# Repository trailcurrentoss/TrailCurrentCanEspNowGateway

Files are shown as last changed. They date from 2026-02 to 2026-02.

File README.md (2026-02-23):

# TrailCurrent CAN to ESP-NOW Gateway

A wireless relay gateway that bridges CAN bus messages to ESP-NOW protocol for remote vehicle monitoring in tow vehicles. Part of the [TrailCurrent](https://trailcurrent.com) open-source vehicle platform.

## Overview

This project enables wireless relaying of CAN bus messages using the ESP-NOW protocol. The gateway hardware and firmware allow real-time data from a trailer's CAN bus to be transmitted reliably to remote displays and monitoring devices in a vehicle.

**Use Case:** Display trailer sensor data (battery voltage, temperature, weight sensors, etc.) on an in-vehicle display while the vehicle and trailer are separated or connected.

## Hardware Overview

- **Function:** Bidirectional CAN-to-ESP-NOW gateway with wireless relay capability
- **Key Features:**
  - CAN bus interface for trailer systems
  - ESP32 with integrated WiFi for robust wireless communication
  - ESP-NOW protocol for low-latency, long-range communication
  - Power management for vehicle and trailer power systems
  - Hierarchical schematic design (5 sheets) for system modularity
  - Compact design for integration into vehicle tow systems

## Hardware Requirements

### Components

- **Microcontroller:**
  - ESP32-WROOM or ESP32-S3 with WiFi and Bluetooth

- **CAN Interface:**
  - CAN transceiver for reliable CAN bus communication
  - Protection circuits for robust automotive operation

- **Power Management:**
  - Buck converter (AP63203WU-7) for regulated power supply
  - Filtering and protection circuits

- **Connectors:**
  - CAN bus interface connectors
  - Power connectors
  - Debug/programming connectors

### KiCAD Library Dependencies

This project uses the consolidated [TrailCurrentKiCADLibraries](https://github.com/trailcurrentoss/TrailCurrentKiCADLibraries).

**Setup:**

```bash
# Clone the library
git clone git@github.com:trailcurrentoss/TrailCurrentKiCADLibraries.git

# Set environment variables (add to ~/.bashrc or ~/.zshrc)
export TRAILCURRENT_SYMBOL_DIR="/path/to/TrailCurrentKiCADLibraries/symbols"
export TRAILCURRENT_FOOTPRINT_DIR="/path/to/TrailCurrentKiCADLibraries/footprints"
export TRAILCURRENT_3DMODEL_DIR="/path/to/TrailCurrentKiCADLibraries/3d_models"
```

See [KICAD_ENVIRONMENT_SETUP.md](https://github.com/trailcurrentoss/TrailCurrentKiCADLibraries/blob/main/KICAD_ENVIRONMENT_SETUP.md) in the library repository for detailed setup instructions.

## Opening the Project

1. **Set up environment variables** (see Library Dependencies above)
2. **Open KiCAD:**
   ```bash
   kicad /path/to/EDA/trailecurrent-can-to-espnow-gateway/trailecurrent-can-to-espnow-gateway.kicad_pro
   ```
3. **Verify libraries load** - All symbol and footprint libraries should resolve without errors
4. **Navigate hierarchical sheets:**
   - Main gateway sheet with module interconnects
   - CAN interface circuit (isolation and termination)
   - ESP32 microcontroller and WiFi section
   - Power management circuits
   - Support and protection circuits
5. **View 3D models** - Open PCB and press `Alt+3` to view the 3D visualization
   - All 3D models should load from the consolidated library path
   - Models use relative `${TRAILCURRENT_3DMODEL_DIR}` references

## Firmware

See `src/` directory for PlatformIO-based firmware implementing CAN-to-ESP-NOW bridging.

**Key Features:**
- CAN message reception and parsing
- ESP-NOW wireless transmission
- Bidirectional communication capability
- Configuration management for CAN filters and routing
- Low-power sleep modes for extended battery life

**Setup:**
```bash
# Install PlatformIO (if not already installed)
pip install platformio

# Build firmware
pio run -d /path/to/project

# Upload to board
pio run -t upload -d /path/to/project

# Monitor serial output
pio device monitor -d /path/to/project
```

**WiFi Credentials:**

The gateway requires WiFi credentials for OTA updates and network communication.

- **Production**: WiFi credentials are delivered via CAN Bus (ID 0x01) from the TrailCurrent system
- **Development**: For standalone testing without the TrailCurrent system, create `src/secrets.h`:

```bash
# Copy the example template
cp src/secrets.h.example src/secrets.h

# Edit with your WiFi credentials
nano src/secrets.h
```

```cpp
// src/secrets.h (DO NOT COMMIT - it's in .gitignore)
const char* ssid = "YOUR_SSID_HERE";
const char* password = "YOUR_PASSWORD_HERE";
uint8_t broadcastAddress[] = {0xXX, 0xXX, 0xXX, 0xXX, 0xXX, 0xXX};
```

**Important:**
- Never commit `src/secrets.h` (it's in .gitignore)
- Use `src/secrets.h.example` as a template
- The gateway MAC address should match your hardware

**Future Enhancement:** WiFi credential configuration will be fully implemented via CAN Bus protocol, allowing credentials to be distributed from the TrailCurrent system without firmware modifications.

## System Architecture

The gateway architecture:

1. **CAN Interface:** Receives messages from trailer CAN bus
2. **ESP32 Processor:** Parses and routes messages based on configured rules
3. **ESP-NOW Radio:** Transmits to remote devices with low latency
4. **Remote Device:** Receives and displays trailer data

Supports multiple remote devices through ESP-NOW group addressing.

## Manufacturing

- **PCB Files:** Ready for fabrication via standard PCB services (JLCPCB, OSH Park, etc.)
- **BOM Generation:** Export BOM from KiCAD schematic (Tools → Generate BOM)
- **JLCPCB Assembly:** This project supports automated assembly using JLCPCB
  - See [BOM_ASSEMBLY_WORKFLOW.md](https://github.com/trailcurrentoss/TrailCurrentKiCADLibraries/blob/main/BOM_ASSEMBLY_WORKFLOW.md) for detailed assembly workflow
  - Component library includes LCSC, Mouser, and DigiKey part numbers for flexible sourcing

## Project Structure

- **EDA/trailecurrent-can-to-espnow-gateway/** - KiCAD schematic (5 sheets) and PCB design files
  - Gateway main sheet with module organization
  - CAN interface and protection circuits
  - ESP32 microcontroller and radio circuits
  - Power management and support circuits
- **src/** - Firmware source code for CAN message bridging and ESP-NOW communication
- **lib/** - Custom libraries and CAN protocol drivers
- **include/** - Header files for configuration and messaging

## Documentation

- **Main Schematic:** EDA/trailecurrent-can-to-espnow-gateway/trailecurrent-can-to-espnow-gateway.kicad_sch (with 5 sheet hierarchy)
- **PCB Layout:** EDA/trailecurrent-can-to-espnow-gateway/trailecurrent-can-to-espnow-gateway.kicad_pcb

## License

MIT License - See LICENSE file for details

This is open source hardware. You are free to use, modify, and distribute these designs for personal or commercial purposes.

## Contributing

Improvements and contributions are welcome! Please submit issues or pull requests to the main repository.

## Support

For questions about:
- **KiCAD setup:** See [KICAD_ENVIRONMENT_SETUP.md](https://github.com/trailcurrentoss/TrailCurrentKiCADLibraries/blob/main/KICAD_ENVIRONMENT_SETUP.md)
- **Library consolidation:** See [CONNECTOR_CONSOLIDATION_SUMMARY.md](https://github.com/trailcurrentoss/TrailCurrentKiCADLibraries/blob/main/CONNECTOR_CONSOLIDATION_SUMMARY.md)
- **Assembly workflow:** See [BOM_ASSEMBLY_WORKFLOW.md](https://github.com/trailcurrentoss/TrailCurrentKiCADLibraries/blob/main/BOM_ASSEMBLY_WORKFLOW.md)

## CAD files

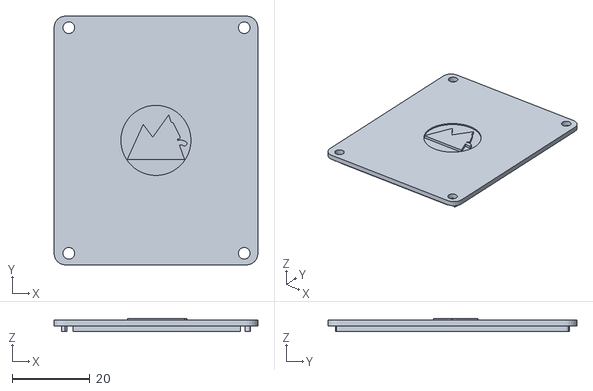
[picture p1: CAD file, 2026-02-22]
CAD/BodyCanToEspNowGatewayCaseCoverV1_WithLogo.stl
52.4 x 64.0 x 3.40

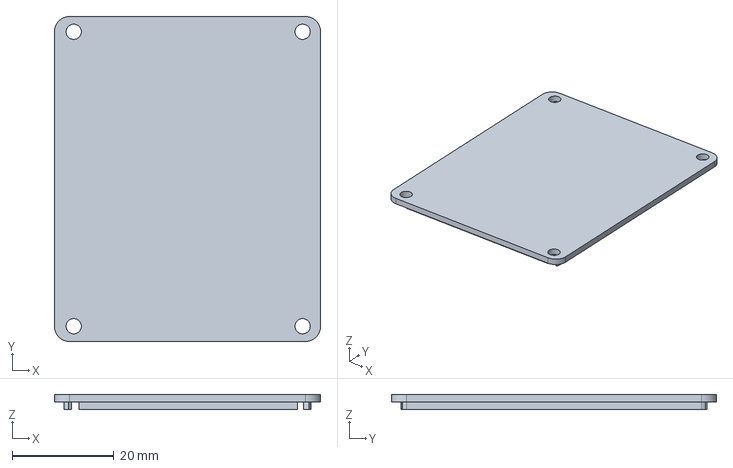
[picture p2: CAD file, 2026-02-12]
CAD/trailcurrent-can-to-espnow-gateway.FCStd
52.4 x 64.0 x 3.00 mm

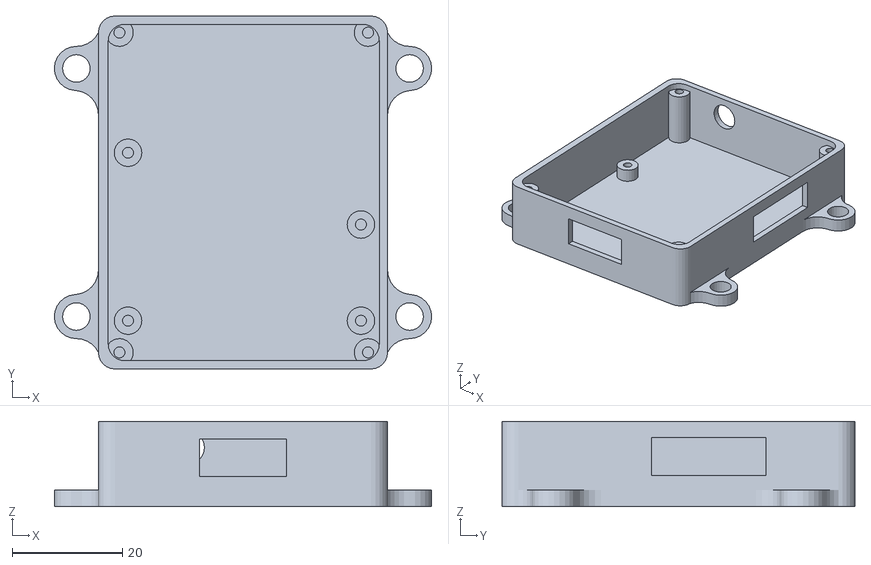
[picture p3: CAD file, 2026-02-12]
CAD/BodyCanToEspNowGatewayCaseBottomV1.stl
68.4 x 64.0 x 15.5

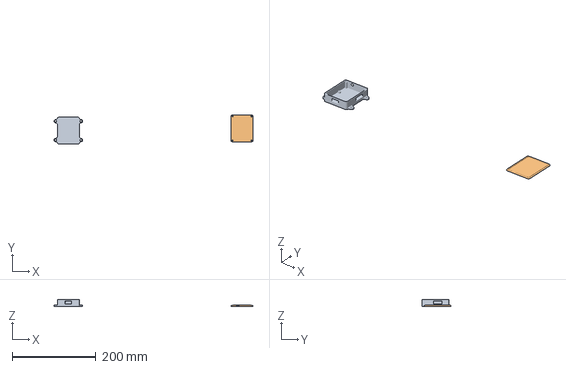
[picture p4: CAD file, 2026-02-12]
CAD/BodyCanToEspNowGatewayCase.3mf
474.1 x 69.4 x 15.5 mm
BodyCanToEspNowGatewayCaseBottomV1.stl
BodyCanToEspNowGatewayCaseCoverV1.stl

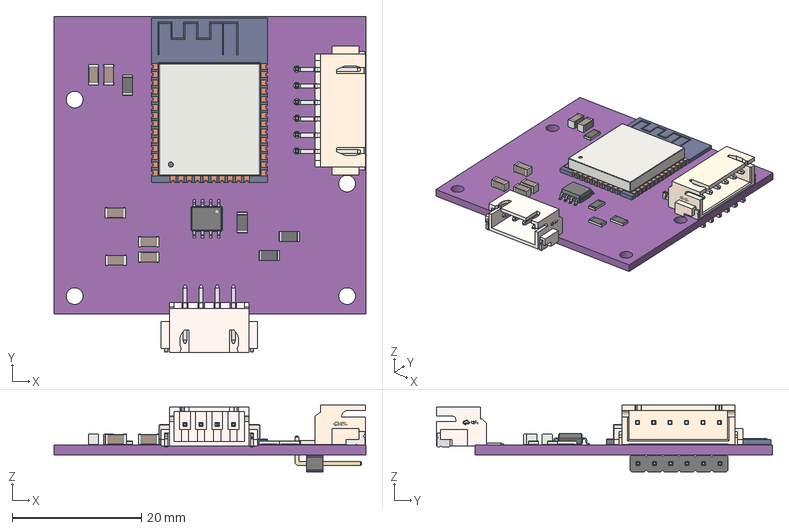
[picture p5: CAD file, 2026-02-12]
CAD/trailer-shunt-can-bus.step
48.4 x 52.1 x 10.3 mm
R_1206_3216Metric x 4
C_1206_3216Metric x 6
SOIC-8_3.9x4.9mm_P1.27mm
ESP32-WROOM-32
CONN-SMD_ZX-XH2.54-6PWT
CONN-SMD_4P-P2.50-WAFER-254W-4P
PinHeader_1x06_P2.54mm_Horizontal
trailecurrent-can-to-espnow-gateway_PCB

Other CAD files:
CAD/BodyCanToEspNowGatewayCaseCoverV1.stl

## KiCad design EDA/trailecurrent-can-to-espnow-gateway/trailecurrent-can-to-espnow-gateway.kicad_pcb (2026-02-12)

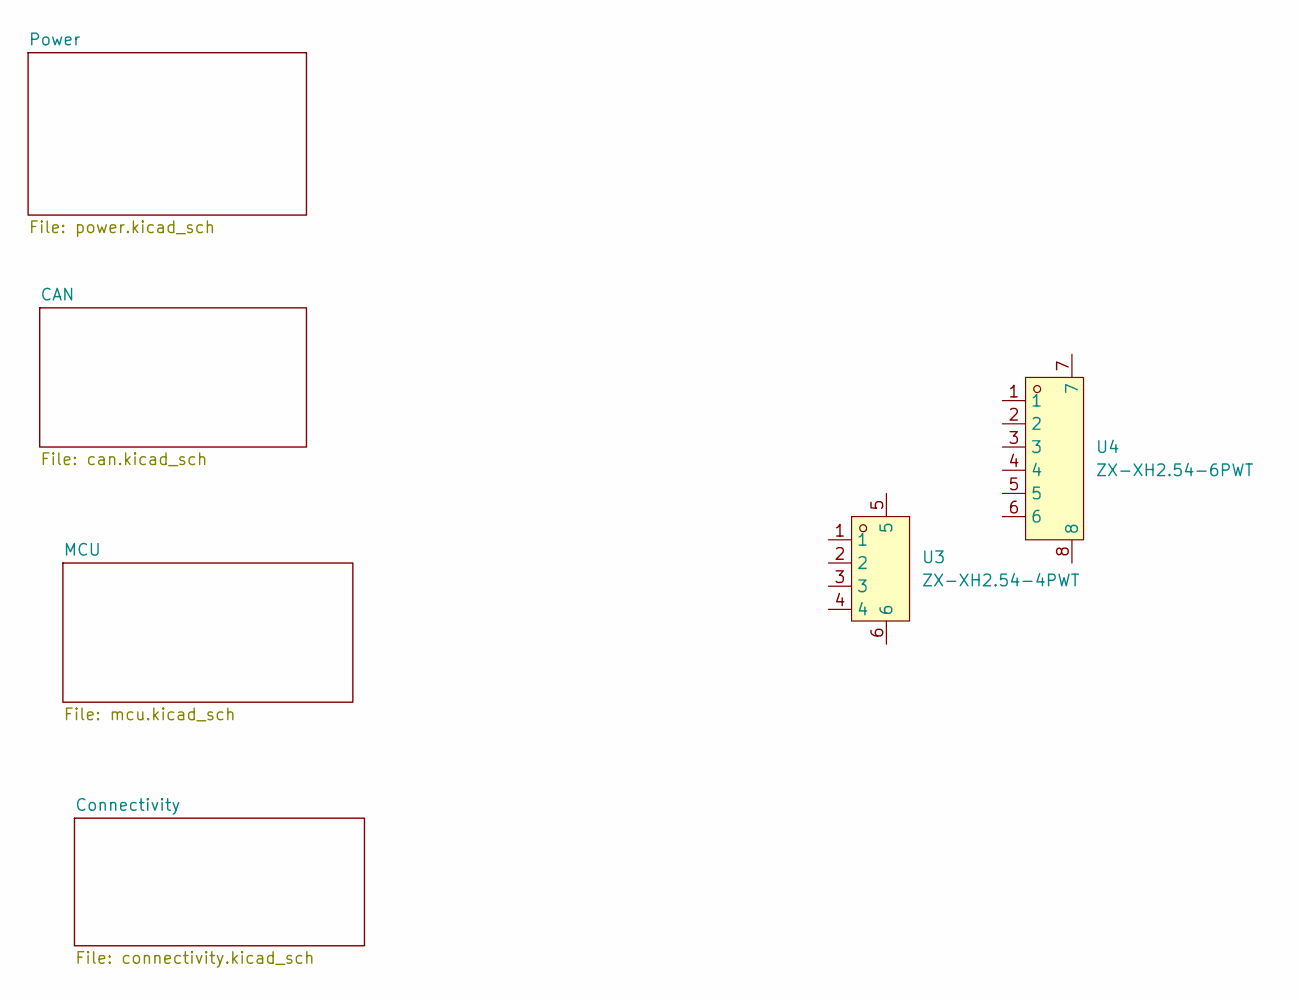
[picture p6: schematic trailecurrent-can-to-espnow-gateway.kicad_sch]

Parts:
U3: ZX-XH2.54-4PWT; CONN-SMD_4P-P2.50-WAFER-254W-4P; LCSC Part C7429673
U4: ZX-XH2.54-6PWT; CONN-SMD_ZX-XH2.54-6PWT; LCSC Part C7429675

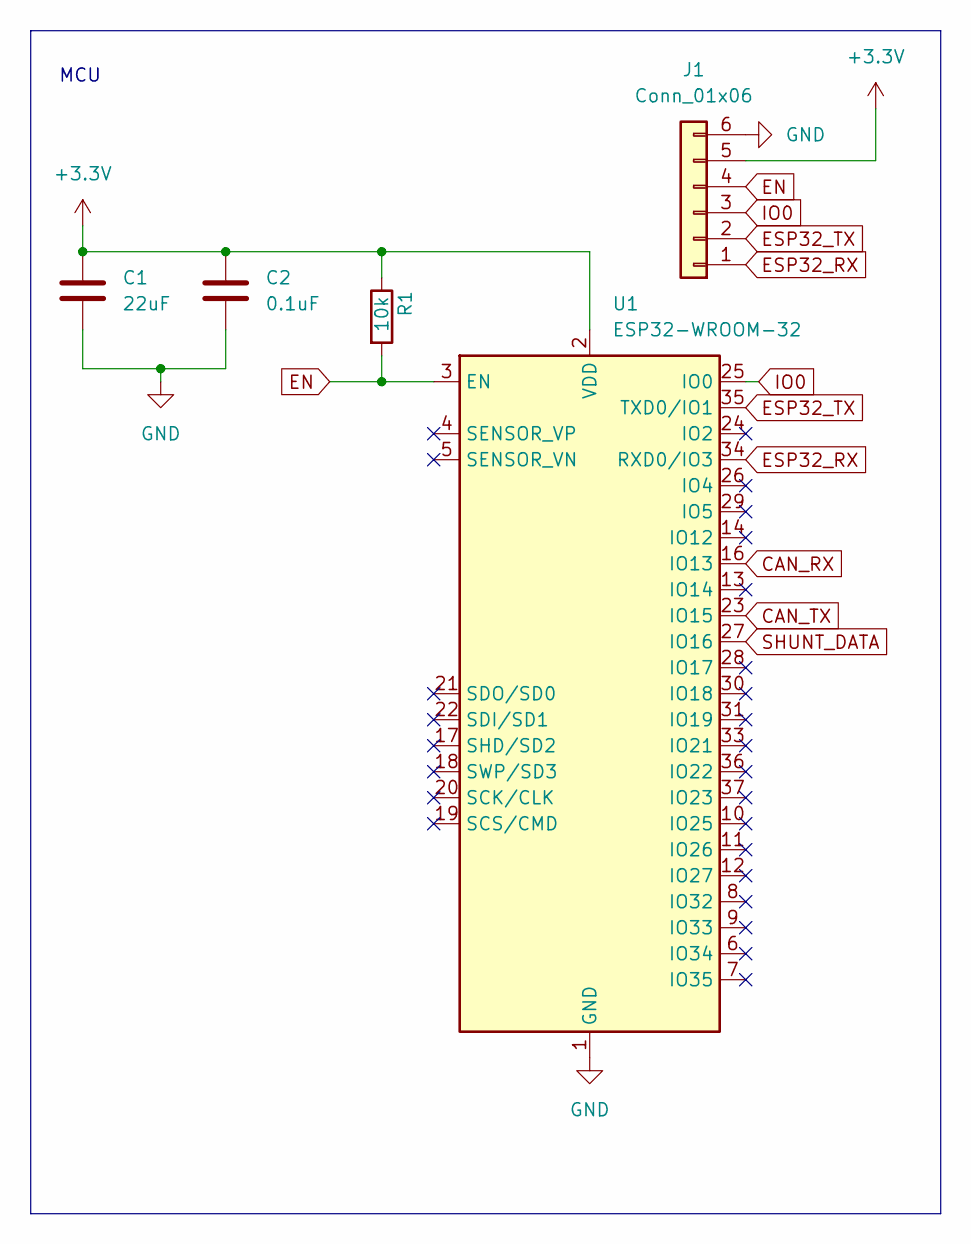
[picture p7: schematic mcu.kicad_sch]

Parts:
C1: 22uF; C_1206_3216Metric_Pad1.33x1.80mm_HandSolder
C2: 0.1uF; C_1206_3216Metric_Pad1.33x1.80mm_HandSolder
J1: Conn_01x06; PinHeader_1x06_P2.54mm_Horizontal
R1: 10k; R_1206_3216Metric_Pad1.30x1.75mm_HandSolder
U1: ESP32-WROOM-32

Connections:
+3.3V: C1.1, C2.1, J1.5, R1.1, U1.2 (VDD); also elsewhere on the board
CAN_RX: U1.16 (IO13); also elsewhere on the board
CAN_TX: U1.23 (IO15); also elsewhere on the board
EN: J1.4, R1.2, U1.3 (EN)
ESP32_RX: J1.1, U1.34 (RXD0/IO3)
ESP32_TX: J1.2, U1.35 (TXD0/IO1)
GND: C1.2, C2.2, J1.6, U1.1 (GND), U1.15 (GND), U1.38 (GND), U1.39 (GND); also elsewhere on the board
IO0: J1.3, U1.25 (IO0)
SHUNT_DATA: U1.27 (IO16); also elsewhere on the board

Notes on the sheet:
MCU

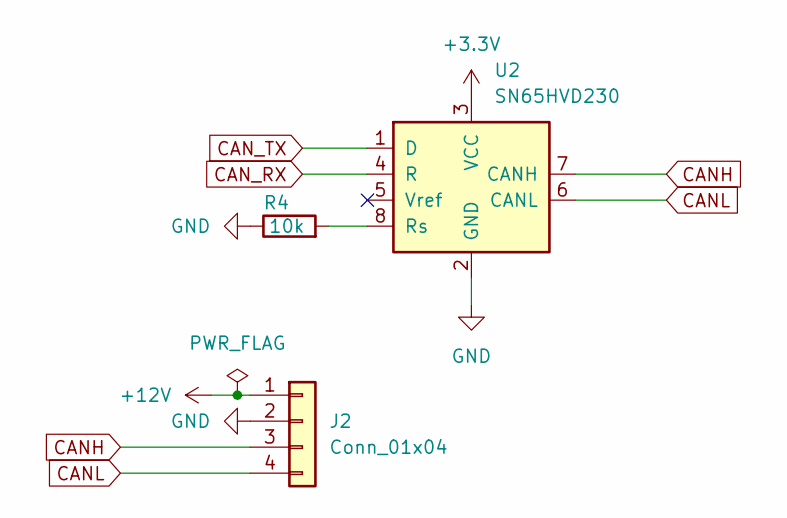
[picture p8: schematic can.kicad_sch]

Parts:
J2: Conn_01x04; CAN_PLUS_POWER
R4: 10k; R_1206_3216Metric_Pad1.30x1.75mm_HandSolder
U2: SN65HVD230; SOIC-8_3.9x4.9mm_P1.27mm

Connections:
+3.3V: U2.3 (VCC); also elsewhere on the board
+12V: J2.1; also elsewhere on the board
CANH: J2.3, U2.7 (CANH)
CANL: J2.4, U2.6 (CANL)
CAN_RX: U2.4 (R); also elsewhere on the board
CAN_TX: U2.1 (D); also elsewhere on the board
GND: J2.2, R4.1, U2.2 (GND); also elsewhere on the board
unnamed: R4.2, U2.8 (Rs)

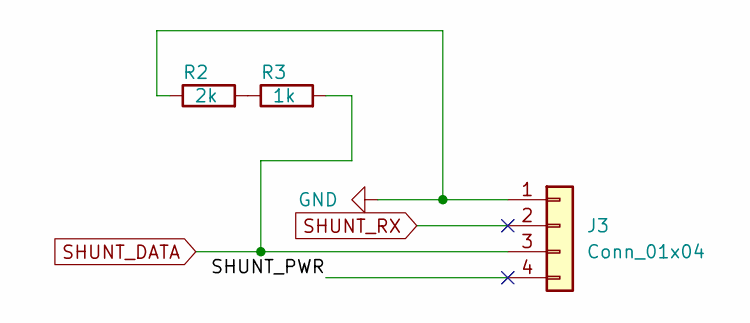
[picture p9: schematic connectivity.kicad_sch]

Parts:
J3: Conn_01x04; GenericPad_01x04
R2: 2k; R_1206_3216Metric_Pad1.30x1.75mm_HandSolder
R3: 1k; R_1206_3216Metric_Pad1.30x1.75mm_HandSolder

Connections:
/Connectivity/SHUNT_PWR: J3.4
GND: J3.1, R2.1; also elsewhere on the board
unnamed: R2.2, R3.1
SHUNT_DATA: J3.3, R3.2; also elsewhere on the board
SHUNT_RX: J3.2

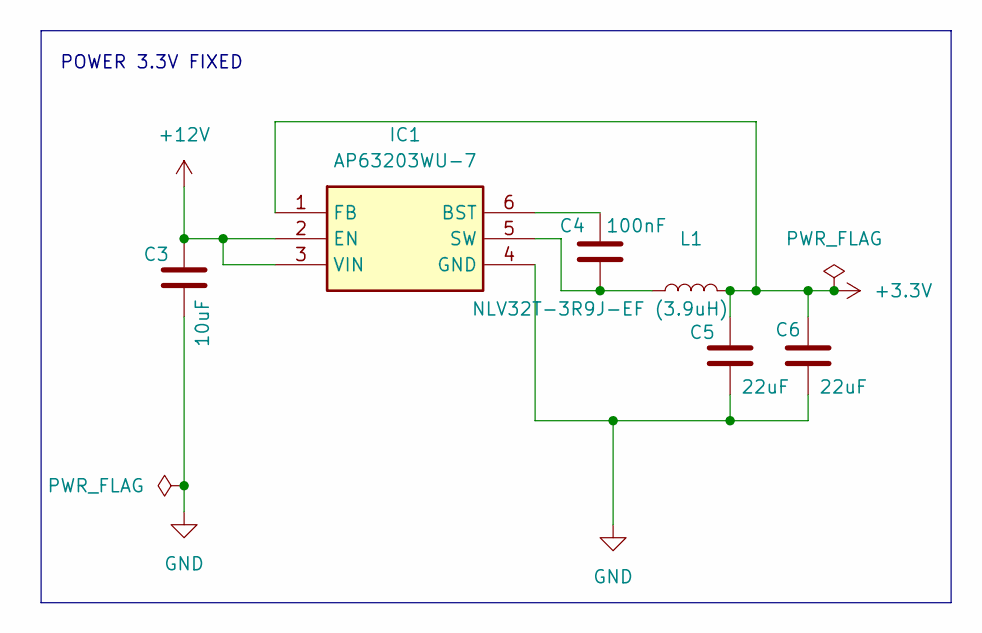
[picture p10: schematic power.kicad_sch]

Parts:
C3: 10uF; C_1206_3216Metric
C4: 100nF; C_1206_3216Metric
C5, C6: 22uF; C_1206_3216Metric_Pad1.33x1.80mm_HandSolder
IC1: AP63203WU-7; AP63203WU7; Mouser Part Number 621-AP63203WU-7
L1: NLV32T-3R9J-EF (3.9uH); NLV32T-3R9J-EF

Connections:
+3.3V: C5.1, C6.1, IC1.1 (FB), L1.2; also elsewhere on the board
+12V: C3.1, IC1.2 (EN), IC1.3 (VIN); also elsewhere on the board
GND: C3.2, C5.2, C6.2, IC1.4 (GND); also elsewhere on the board
unnamed: C4.1, IC1.6 (BST)
unnamed: C4.2, IC1.5 (SW), L1.1

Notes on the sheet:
POWER 3.3V FIXED

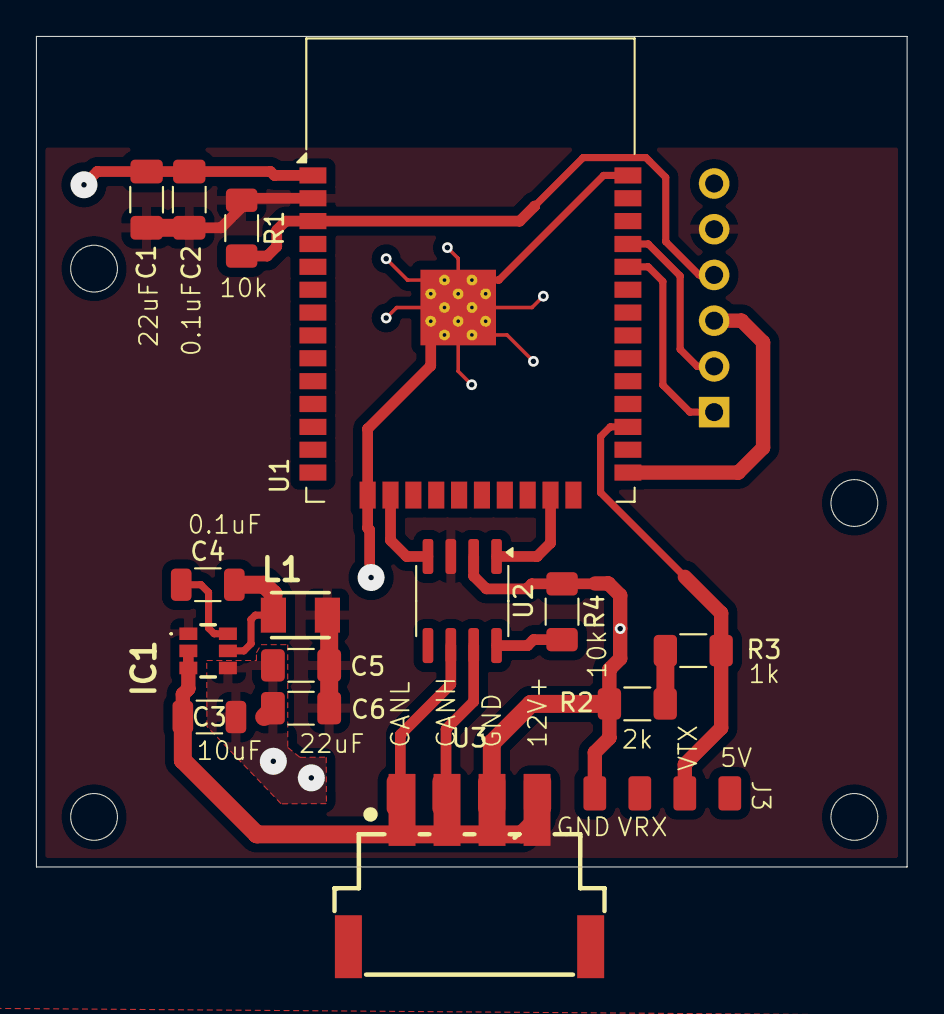
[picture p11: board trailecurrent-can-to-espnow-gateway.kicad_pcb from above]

Board: 2 copper layers, 48.4 x 46.1 mm, 18 parts (1 on the bottom side), 16 nets.

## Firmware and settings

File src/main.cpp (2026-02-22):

#include "globals.h"
#include "canHelper.h"
#include "espNowHelper.h"
#include <OtaUpdate.h>
#include <Preferences.h>

// Create OTA update handler (3-minute timeout, 180000 ms)
// Credentials are loaded from NVS when OTA is triggered; empty here for getHostName() only
OtaUpdate otaUpdate(180000, "", "");

void setup()
{
  Serial.begin(115200);
  delay(1000);  // Give serial time to initialize

  debugln("\n=== TrailCurrent CAN-to-ESPNow Gateway ===");
  debugln("CAN to ESP-NOW Bridge with OTA Updates");

  // Initialize CAN bus
  debugln("[CAN] Initializing CAN bus...");
  canHelper::initialize();

  // Initialize OTA (connects to WiFi)
  String hostname = otaUpdate.getHostName();

  debugf("[OTA] Device hostname: %s\n", hostname.c_str());
  debugln("[OTA] Ready to receive OTA trigger (CAN ID 0x0)");
  debugln("[OTA] OTA trigger format: CAN ID=0x0, Data[0:2]=MAC bytes matching device hostname");

  // Initialize ESPNow
  debugln("[ESPNOW] Initializing ESP-NOW...");
  espNowHelper::initialize();

  delay(500);
  debugf("[WIFI] Connected: %s\n", WiFi.isConnected() ? "YES" : "NO");
  if (WiFi.isConnected()) {
    debugf("[WIFI] IP: %s\n", WiFi.localIP().toString().c_str());
  }

  debugln("=== Setup Complete ===\n");
}

void loop()
{
  canHelper::checkCanBusForMessages();
  delay(10);
}

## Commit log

2026-02-12 Initial commit: Clean migration to public Codeberg repository
    This is a fresh start on Codeberg with all security and configuration
    issues addressed:
    Security fixes:
    - Removed all git history (fresh start)
    - No personal paths or credentials exposed
    - All WiFi secrets in .gitignore (using secrets.h.example pattern)
    - Private keys protected
    - Internal URLs replaced with public Codeberg references
    Configuration updates:
    - Updated all GitHub references to Codeberg
    - KiCAD projects use environment variables for library paths
    - Platform IO dependencies point to public repositories
    - All .gitignore files comprehensive
    Ready for public use.
    [BodyCanToEspNowGatewayCase.3mf, BodyCanToEspNowGatewayCaseBottomV1.stl, BodyCanToEspNowGatewayCaseCoverV1.stl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]
2026-02-22 Secrets removed updated to get WiFi from OTA
    [BodyCanToEspNowGatewayCaseCoverV1_WithLogo.stl]
